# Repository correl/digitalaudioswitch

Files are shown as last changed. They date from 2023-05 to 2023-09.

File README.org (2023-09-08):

#+title: Audio Input and Volume Control

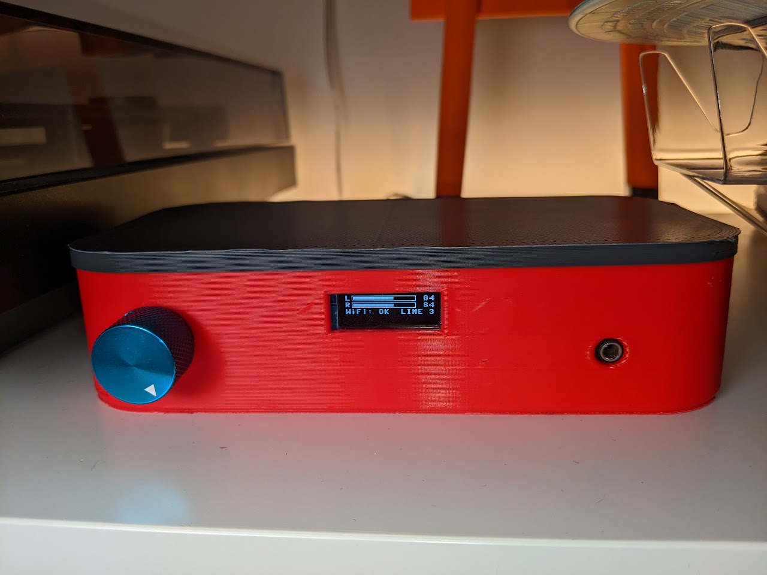
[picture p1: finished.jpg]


* Features
- Switches between three external inputs, outputting through the 3.5mm LINE OUT
  jack.
- Volume control and input switching can be done using the pressable dial on the front
- Current status is displayed on a 128x32 OLED display
- Can be fully controlled via Home Assistant as an [[https://www.home-assistant.io/integrations/mqtt/][MQTT-discoverable]] device.
* Firmware
** Configuration
Create a file named =settings.json= in the project directory with WiFi and MQTT
connection information.

#+begin_src js
  {
      "wifi": {
          "ssid": "MY-SSID",
          "password": "my-wifi-password"
      },
      "mqtt": {
          "broker": "192.168.1.123",
          "prefix": "digital-audio-switch"
      }
  }
#+end_src
** Deploying
Connect the ESP32 to your computer. If you haven't already, [[https://micropython.org/download/esp32/][flash it with the
latest version of MicroPython]], and ensure you have [[https://docs.micropython.org/en/latest/reference/mpremote.html][mpremote installed]].

Running =make= will install dependencies and copy the code and configuration to
the ESP32, resetting it when done.
* Circuit Design
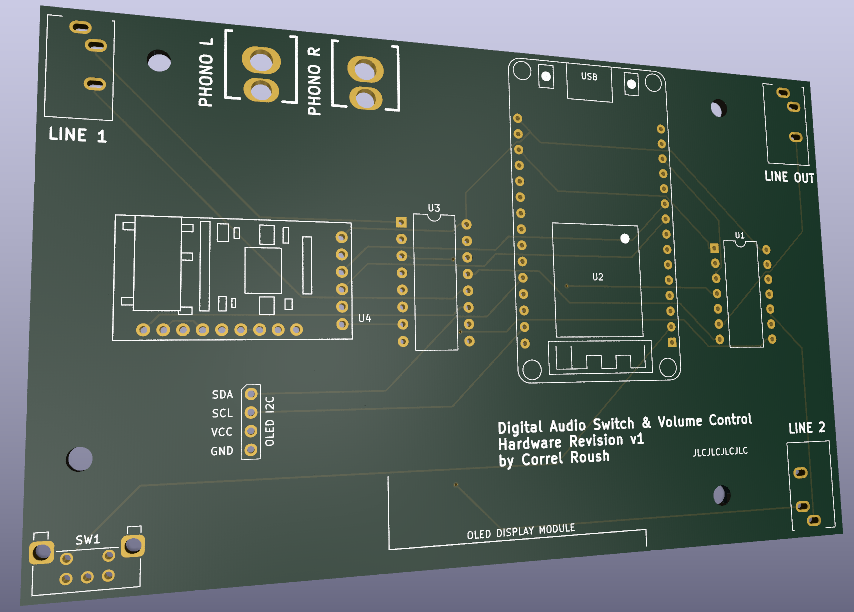
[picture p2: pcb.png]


The schematic and board layout can be found in the [[file:kicad/][kicad]] folder.
* Case
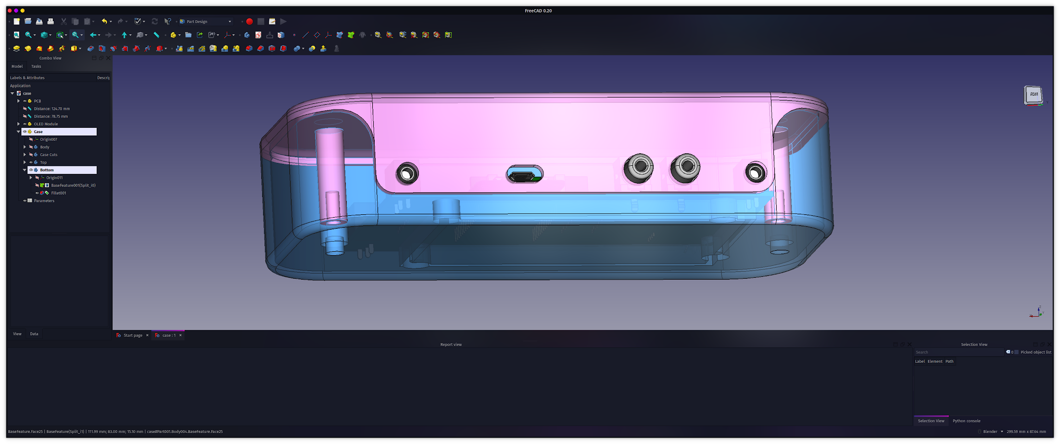
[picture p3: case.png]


The 3D-printable case is built using FreeCAD and can be found in the [[file:freecad/][freecad]]
folder. It is divided into a top and bottom piece. The PCB is affixed using four
M3 threaded inserts and 6mm M3 bolts, the case is assembled using 2 M3 threaded
inserts and 2 10mm M3 bolts.

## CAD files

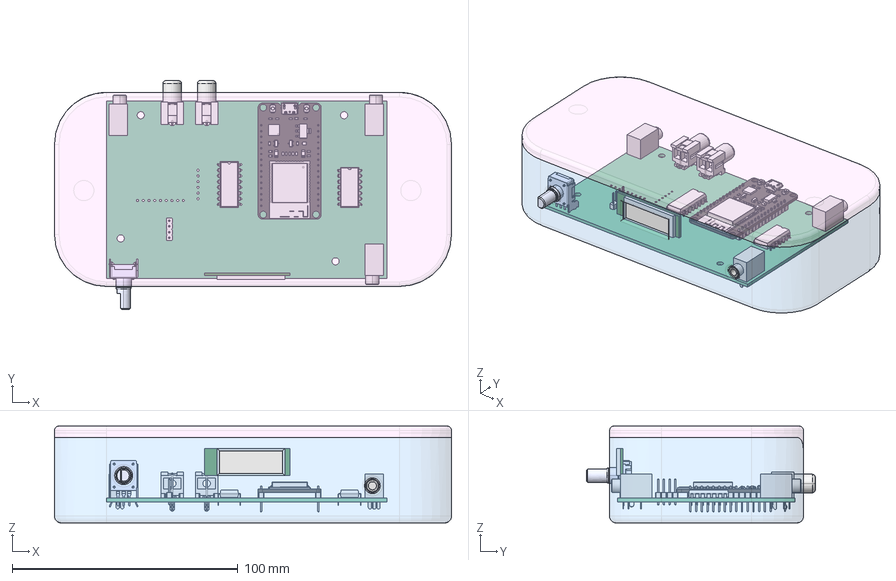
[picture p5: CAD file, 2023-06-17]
freecad/case.FCStd
176.0 x 101.4 x 43.0 mm
Pcb_879ee
J3_CUI_DEVICES_SJ1-3533NG_4473374c59b9 x 3
U3_DIP_16_W1016mm_c0b8a379621b
U2_SW_SPST_B3U-1000P-B_d01e381b36a0 x 2
U2_PinHeader_1x15_P254mm_Vertical_d01e381b36a0[3] x 2
U2_PCB_d01e381b36a0[5]
U2_USB_Micro-B_Molex_47346-0001_d01e381b36a0[6]
U2_LED_1206_3216Metric_d01e381b36a0[7] x 2
U2_CP_EIA_2012_15_AVX_P_d01e381b36a0[9]
U2_SOT_223_d01e381b36a0[10]
U2_R_0603_1608Metric_d01e381b36a0[11] x 12
U2_SOT_23_d01e381b36a0[14] x 2
U2_C_0603_1608Metric_d01e381b36a0[18] x 3
U2_D_0603_d01e381b36a0[19]
U2_QFN-28-1EP_5x5mm_Pitch0.5mm_d01e381b36a0[25]
U2_ESP32-WROOM-32_d01e381b36a0[30]
J4_KLPX_0848A_2_x_a0df84c5cc1c x 2
SW1_PEC12R-2220F-S0024_f3370e811a44
J6_PinHeader_1x04_P254mm_Vertical_046e1bb5b14f
U1_DIP_14_W1016mm_aa2eb500133f
PCB001
Glass
Top
Bottom

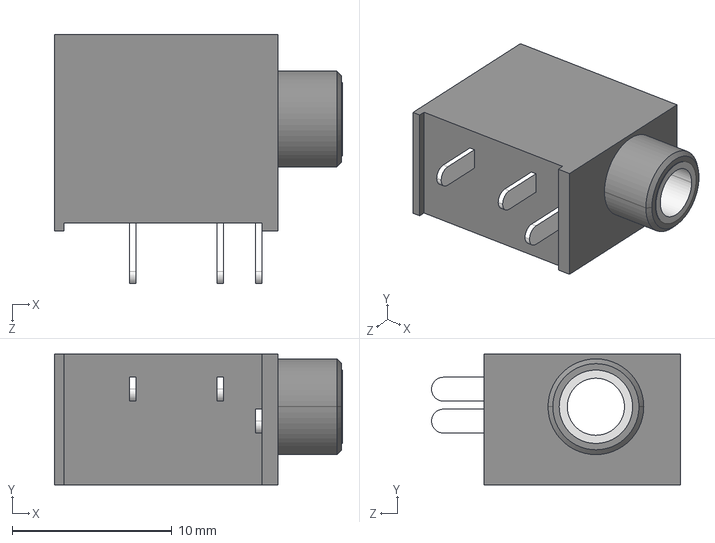
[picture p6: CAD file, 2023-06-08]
kicad/CUI_DEVICES_SJ1-3533NG.step
18.1 x 8.20 x 15.6 mm

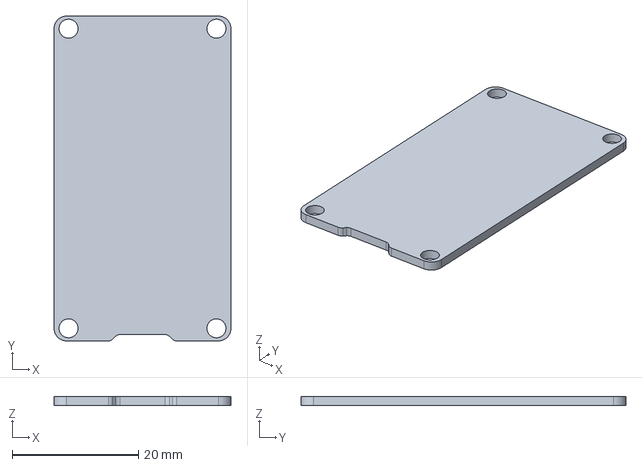
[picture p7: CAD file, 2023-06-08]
kicad/esp32_devkit_v1_doit.step
28.0 x 51.4 x 1.50 mm

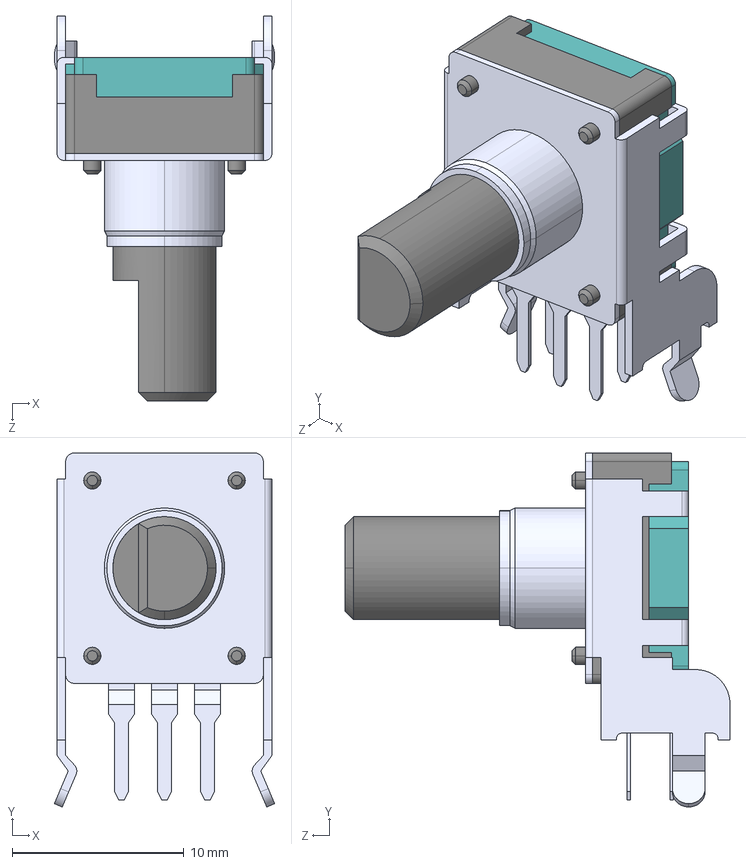
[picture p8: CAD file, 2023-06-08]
kicad/PEC12R-2220F-S0024--3DModel-STEP-1.STEP
12.8 x 20.6 x 22.4 mm

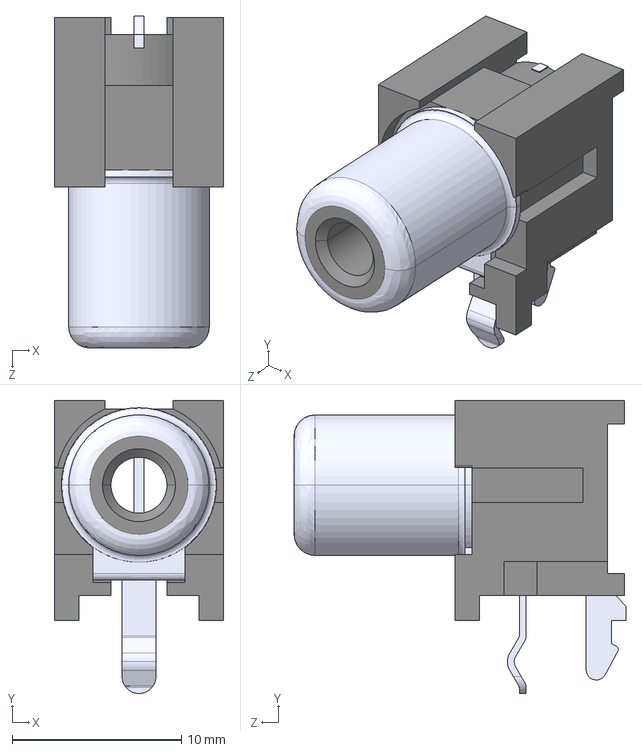
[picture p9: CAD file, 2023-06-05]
kicad/KLPX-0848A-2-x.IGS
10.0 x 17.3 x 19.6 mm

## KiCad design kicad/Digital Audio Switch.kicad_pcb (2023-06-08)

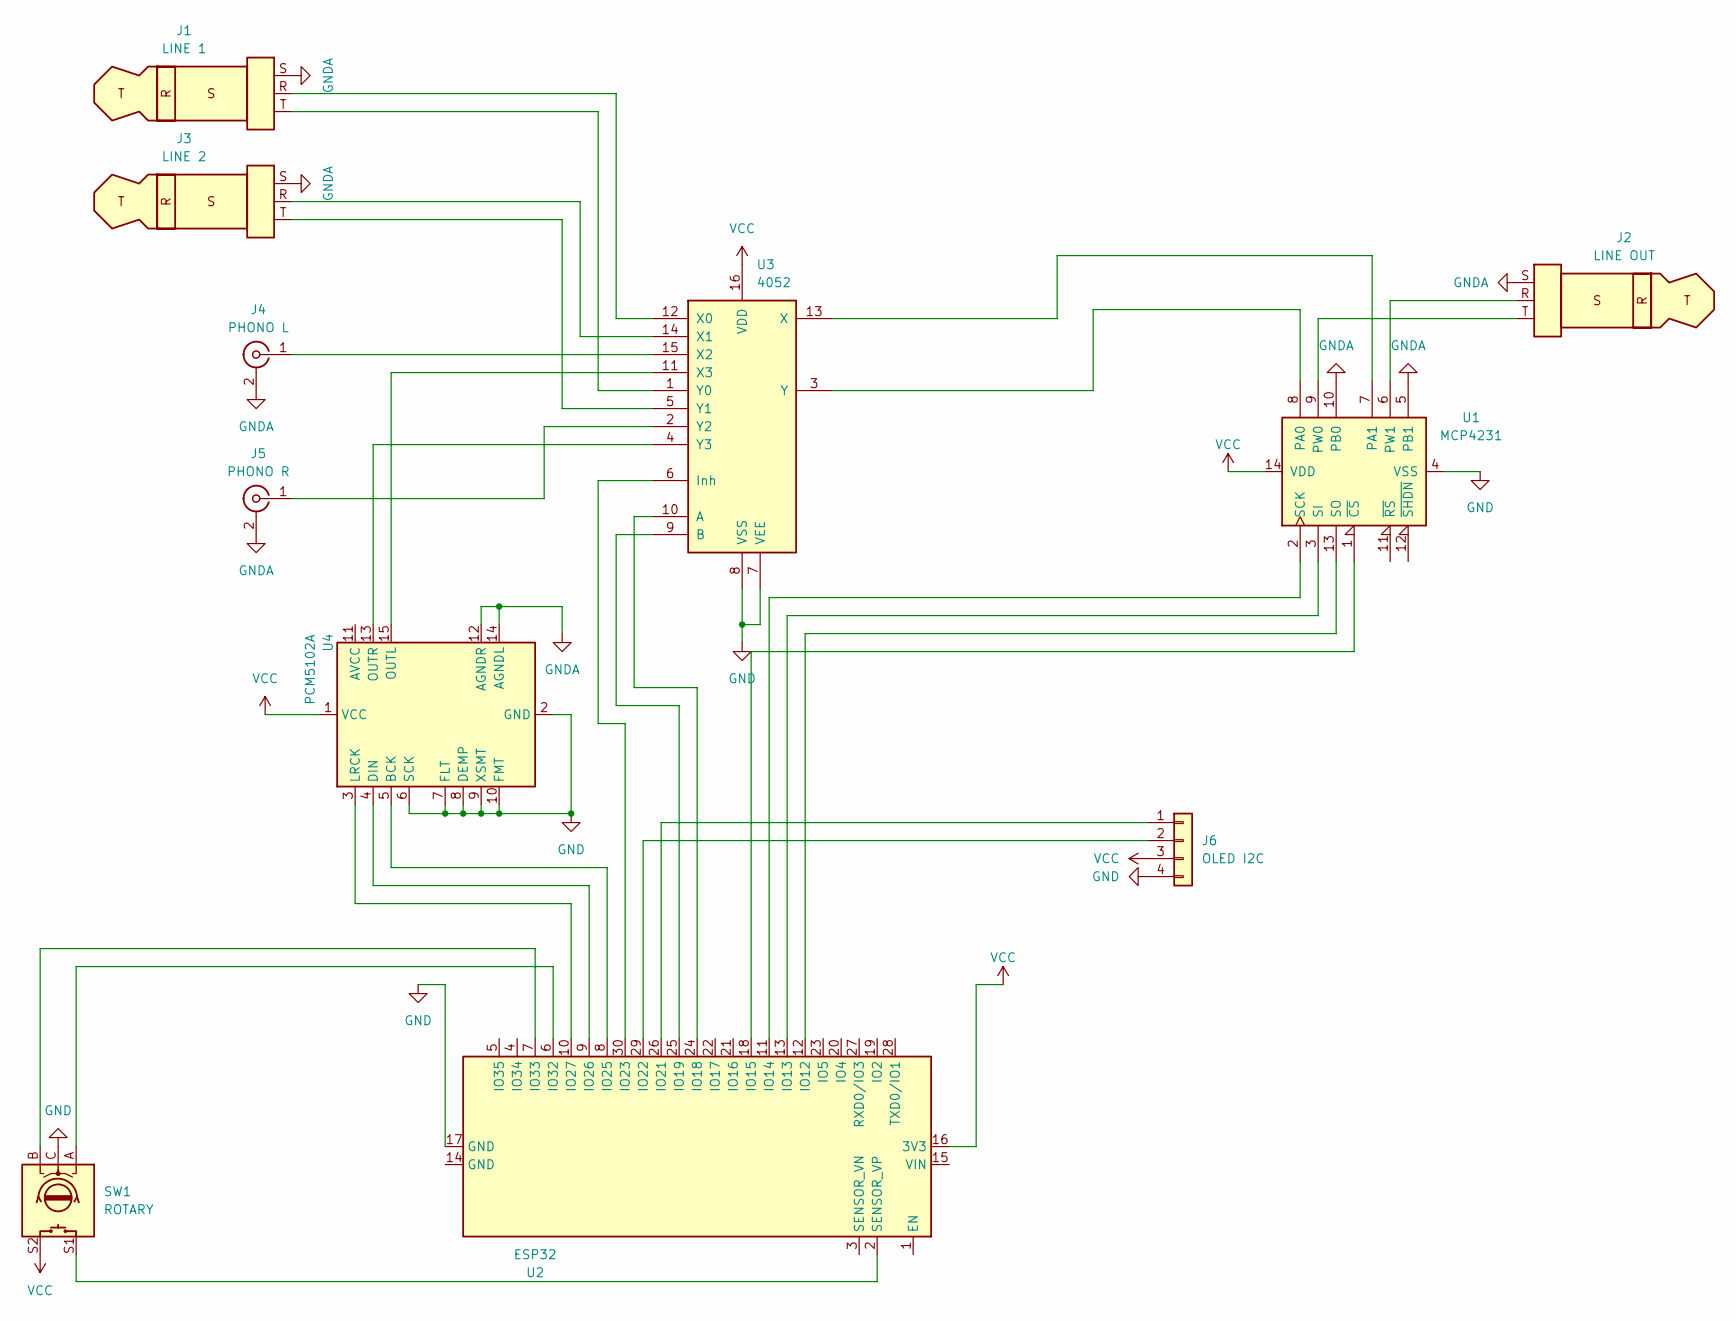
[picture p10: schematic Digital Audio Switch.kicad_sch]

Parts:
J1: LINE 1; Jack_3.5mm_CUI_SJ1-3533NG_Horizontal
J2: LINE OUT; Jack_3.5mm_CUI_SJ1-3533NG_Horizontal
J3: LINE 2; Jack_3.5mm_CUI_SJ1-3533NG_Horizontal
J4: PHONO L; KLPX-0848A
J5: PHONO R; KLPX-0848A
J6: OLED I2C; I2C Pin Header
SW1: ROTARY; RotaryEncoder_Bourns_Horizontal_PEC12R-2xxxF-Sxxxx
U1: MCP4231; DIP-14_W10.16mm
U2: ESP32; esp32_devkit_v1_doit
U3: 4052; DIP-16_W10.16mm
U4: PCM5102A; PCM5102

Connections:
GND: J6.4, SW1.C, U1.4 (VSS), U2.17 (GND), U3.7 (VEE), U3.8 (VSS), U4.2 (GND), U4.6 (SCK), U4.7 (FLT), U4.8 (DEMP), U4.9 (XSMT), U4.10 (FMT)
GNDA: J1.S, J2.S, J3.S, J4.2 (Ext), J5.2 (Ext), U1.5 (PB1), U1.10 (PB0), U4.12 (AGNDR), U4.14 (AGNDL)
unnamed: J4.1 (In), U3.15 (X2)
unnamed: J5.1 (In), U3.2 (Y2)
unnamed: J6.1, U2.26 (IO21)
unnamed: J6.2, U2.29 (IO22)
unnamed: U1.8 (PA0), U3.3 (Y)
unnamed: U1.7 (PA1), U3.13 (X)
unnamed: J2.T, U1.9 (PW0)
unnamed: J2.R, U1.6 (PW1)
unnamed: U1.2 (SCK), U2.11 (IO14)
unnamed: U1.3 (SI), U2.13 (IO13)
unnamed: U1.13 (SO), U2.12 (IO12)
unnamed: U1.1 (~CS), U2.18 (IO15)
unnamed: U2.24 (IO18), U3.10 (A)
unnamed: U2.25 (IO19), U3.9 (B)
unnamed: U2.30 (IO23), U3.6 (Inh)
unnamed: U2.8 (IO25), U4.5 (BCK)
unnamed: U2.9 (IO26), U4.4 (DIN)
unnamed: U2.10 (IO27), U4.3 (LRCK)
unnamed: SW1.A, U2.6 (IO32)
unnamed: SW1.B, U2.7 (IO33)
unnamed: SW1.S1, U2.2 (SENSOR_VP)
unnamed: J1.R, U3.12 (X0)
unnamed: J3.R, U3.14 (X1)
unnamed: U3.11 (X3), U4.15 (OUTL)
unnamed: J1.T, U3.1 (Y0)
unnamed: J3.T, U3.5 (Y1)
unnamed: U3.4 (Y3), U4.13 (OUTR)
VCC: J6.3, SW1.S2, U1.14 (VDD), U2.16 (3V3), U3.16 (VDD), U4.1 (VCC)

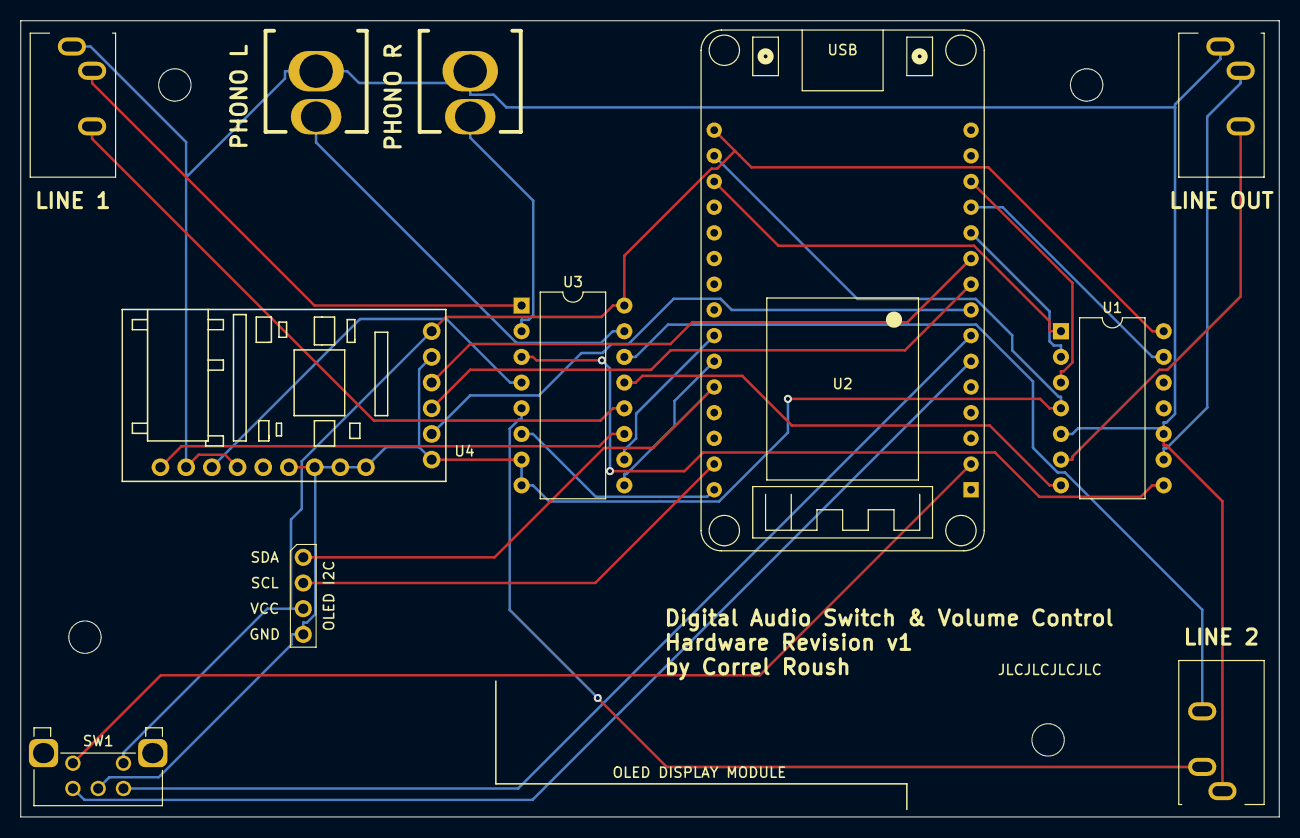
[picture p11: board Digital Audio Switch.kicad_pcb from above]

Board: 2 copper layers, 124.5 x 78.7 mm, 15 parts (0 on the bottom side), 30 nets.

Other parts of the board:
H1, H2, H3, H4: MountingHole_3.2mm_M3

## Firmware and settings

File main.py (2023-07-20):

from machine import Pin, SPI, SoftI2C
import framebuf
import json
import machine
import network
import ubinascii
import uasyncio
import utime

from umqtt.simple import MQTTClient

import cd4052
import ssd1306
import mcp4
from button import Button
from rotary_irq_esp import RotaryIRQ
from statetree import StateTree

VOLUME_MAX = const(128)

MQTT_KEEPALIVE = const(60)
MQTT_UPDATE_INTERVAL = const(60)
MQTT_RECONNECT_INTERVAL = const(60)

channels = ["LINE 1", "LINE 2", "PHONO", "DAC"]
state = StateTree(
    {
        "network": "OFF",
        "volume": {
            "left": 0,
            "right": 0,
            "muted": "OFF",
        },
        "channel": channels[0],
    }
)
last_update = 0

rotary = RotaryIRQ(
    33,
    32,
    0,
    max_val=128,
    range_mode=RotaryIRQ.RANGE_BOUNDED,
    pull_up=True,
    incr=4,
)
rotary_value = rotary.value()
rotary_button = Button(Pin(36, Pin.IN))

try:
    i2c = SoftI2C(sda=Pin(21), scl=Pin(22))
    oled_width = const(128)
    oled_height = const(32)
    oled = ssd1306.SSD1306_I2C(oled_width, oled_height, i2c)
except Exception as e:
    print("WARNING: OLED unavailable:", e)
    oled = None

switch = cd4052.CD4052(18, 19, 23)
switch.select(0)

sta_if = network.WLAN(network.STA_IF)

spi = SPI(1)
cs = Pin(15, mode=Pin.OUT, value=1)
pot = mcp4.MCP4(spi, cs)

with open("settings.json", "r") as f:
    settings = json.load(f)

mqtt = None
mqtt_client_id = ubinascii.hexlify(machine.unique_id())
mqtt_broker = settings["mqtt"]["broker"]
mqtt_prefix = settings["mqtt"]["prefix"]
last_mqtt_attempt = 0


def mqtt_init():
    print("Starting MQTT client")
    mqtt = MQTTClient(mqtt_client_id, mqtt_broker, keepalive=MQTT_KEEPALIVE)
    mqtt.set_callback(on_message)
    mqtt.set_last_will(f"{mqtt_prefix}/status", b"offline", retain=True)
    mqtt.connect()
    mqtt.subscribe(f"{mqtt_prefix}/set")
    mqtt_device = {
        "identifiers": mqtt_client_id,
        "manufacturer": "correl",
        "model": "digital-audio-switch",
        "name": "Digital Audio Switch",
    }

    mqtt.publish(
        f"homeassistant/number/digital-audio-switch/volume-left/config".encode(),
        json.dumps(
            {
                "name": "Digital Audio Switch Volume (Left)",
                "command_topic": f"{mqtt_prefix}/set",
                "command_template": '{"volume": {"left": {{value}}}}',
                "state_topic": f"{mqtt_prefix}/state",
                "value_template": "{{ value_json.volume.left }}",
                "availability_topic": f"{mqtt_prefix}/status",
                "min": 0,
                "max": VOLUME_MAX,
                "mode": "slider",
                "step": 1,
                "unique_id": "digital-audio-switch-volume-left",
                "device": mqtt_device,
            }
        ).encode(),
        retain=True,
    )
    mqtt.publish(
        f"homeassistant/number/digital-audio-switch/volume-right/config".encode(),
        json.dumps(
            {
                "name": "Digital Audio Switch Volume (Right)",
                "command_topic": f"{mqtt_prefix}/set",
                "command_template": '{"volume": {"right": {{value}}}}',
                "state_topic": f"{mqtt_prefix}/state",
                "value_template": "{{ value_json.volume.right }}",
                "availability_topic": f"{mqtt_prefix}/status",
                "min": 0,
                "max": VOLUME_MAX,
                "mode": "slider",
                "step": 1,
                "unique_id": "digital-audio-switch-volume-right",
                "device": mqtt_device,
            }
        ).encode(),
        retain=True,
    )
    mqtt.publish(
        f"homeassistant/number/digital-audio-switch/volume-master/config".encode(),
        json.dumps(
            {
                "name": "Digital Audio Switch Volume (Master)",
                "command_topic": f"{mqtt_prefix}/set",
                "command_template": '{"volume": {"right": {{value}}, "left": {{value}}}}',
                "state_topic": f"{mqtt_prefix}/state",
                "value_template": """
                            {%set values = value_json.volume.left,
                                           value_json.volume.right %}
                            {{ values|max }}
                        """,
                "availability_topic": f"{mqtt_prefix}/status",
                "min": 0,
                "max": VOLUME_MAX,
                "mode": "slider",
                "step": 1,
                "unique_id": "digital-audio-switch-volume-master",
                "device": mqtt_device,
            }
        ).encode(),
        retain=True,
    )
    mqtt.publish(
        f"homeassistant/switch/digital-audio-switch/mute/config".encode(),
        json.dumps(
            {
                "name": "Digital Audio Switch Mute",
                "command_topic": f"{mqtt_prefix}/set",
                "payload_on": '{"volume": {"muted": "ON"}}',
                "payload_off": '{"volume": {"muted": "OFF"}}',
                "state_on": "ON",
                "state_off": "OFF",
                "state_topic": f"{mqtt_prefix}/state",
                "value_template": "{{ value_json.volume.muted }}",
                "availability_topic": f"{mqtt_prefix}/status",
                "unique_id": "digital-audio-switch-volume-mute",
                "device": mqtt_device,
            }
        ).encode(),
        retain=True,
    )
    mqtt.publish(
        f"homeassistant/select/digital-audio-switch/channel/config".encode(),
        json.dumps(
            {
                "name": "Digital Audio Switch Channel",
                "command_topic": f"{mqtt_prefix}/set",
                "command_template": '{"channel": "{{value}}"}',
                "state_topic": f"{mqtt_prefix}/state",
                "value_template": "{{ value_json.channel }}",
                "availability_topic": f"{mqtt_prefix}/status",
                "options": channels,
                "unique_id": "digital-audio-switch-channel",
                "device": mqtt_device,
            }
        ).encode(),
        retain=True,
    )
    return mqtt


def on_message(topic, msg):
    print(f"MQTT <- [{topic}] {msg}")
    try:
        msg = json.loads(msg)
    except:
        return
    if volume := msg.get("volume"):
        if isinstance(volume.get("left"), int):
            pot.write(0, volume["left"])
        if isinstance(volume.get("right"), int):
            pot.write(1, volume["right"])
        if isinstance(volume.get("muted"), str):
            switch.mute(volume["muted"] == "ON")
    if isinstance(msg.get("channel"), str):
        try:
            switch.select(channels.index(msg["channel"]))
        except ValueError:
            print("WARNING: Attempted to select invalid channel", msg["channel"])


def loop():
    global mqtt, state, last_update, last_mqtt_attempt
    global rotary, rotary_button, rotary_value

    rotary_button.update()
    if rotary_button.was_clicked():
        switch.toggle_mute()
    if rotary_button.was_double_clicked():
        if switch.channel() >= 3:
            switch.select(0)
        else:
            switch.select(switch.channel() + 1)

    state["volume"]["left"] = pot.read(0)
    state["volume"]["right"] = pot.read(1)
    state["volume"]["muted"] = "ON" if switch.muted() else "OFF"
    state["channel"] = channels[switch.channel()]

    if state.changed:
        # Volume changed externally
        rotary.set(value=max(state["volume"]["left"], state["volume"]["right"]))
        rotary_value = rotary.value()

    new_value = rotary.value()
    if rotary_value != new_value:
        print("Rotary:", new_value)
        state["volume"]["left"] = new_value
        state["volume"]["right"] = new_value
        pot.write(0, new_value)
        pot.write(1, new_value)
        rotary_value = new_value

    if not sta_if.active():
        print("Connecting to WiFi")
        sta_if.active(True)
        sta_if.connect(settings["wifi"]["ssid"], settings["wifi"]["password"])

    if sta_if.active() and not sta_if.isconnected():
        state["network"] = "ACT"
    if sta_if.isconnected():
        ip, _, _, _ = sta_if.ifconfig()
        if ip == "0.0.0.0":
            # Something went wrong, try to reconnect
            print("IP invalid, retrying WiFi connection")
            state["network"] = "ACT"
            sta_if.active(True)
            sta_if.connect(settings["wifi"]["ssid"], settings["wifi"]["password"])
        elif state["network"] != "OK":
            print(f"WIFI Connected to {sta_if.config('ssid')}")
            print(f"IP Address: {ip}")
            state["network"] = "OK"
        if not mqtt and utime.time() - last_mqtt_attempt >= MQTT_RECONNECT_INTERVAL:
            last_mqtt_attempt = utime.time()
            try:
                mqtt = mqtt_init()
            except OSError as e:
                print(f"Failed to connect to MQTT ({mqtt_broker}): {e}")
        if mqtt:
            if state.changed or utime.time() - last_update >= MQTT_UPDATE_INTERVAL:
                topic = f"{mqtt_prefix}/state".encode()
                payload = json.dumps(state.dictionary).encode()
                print(f"MQTT -> [{topic}] {payload}")
                mqtt.publish(f"{mqtt_prefix}/status", b"online", retain=True)
                mqtt.publish(topic, payload, retain=True)
                last_update = utime.time()
            mqtt.check_msg()
    if oled and state.changed:
        oled.fill(0)
        oled.framebuf.rect(10, 0, 92, 8, 1)
        oled.framebuf.rect(
            12, 2, round(state["volume"]["left"] / VOLUME_MAX * 88), 4, 1, True
        )
        oled.framebuf.rect(10, 10, 92, 8, 1)
        oled.framebuf.rect(
            12, 12, round(state["volume"]["right"] / VOLUME_MAX * 88), 4, 1, True
        )
        oled.text("L", 0, 0)
        oled.text("R", 0, 10)
        oled.text(f"{state['volume']['left']:3d}", 104, 0)
        oled.text(f"{state['volume']['right']:3d}", 104, 10)
        if state["volume"]["muted"] == "ON":
            oled.framebuf.rect(40, 4, 4 * 8 + 2, 10, 0, True)
            oled.framebuf.rect(39, 3, 4 * 8 + 4, 12, 1)
            oled.framebuf.rect(38, 2, 4 * 8 + 6, 14, 0)
            oled.text("MUTE", 41, 5)
        oled.text(f"WiFi: {state['network']}", 0, 20)
        oled.text(f'{state["channel"]:>6}', 80, 20)
        oled.show()
    state.clean()


while True:
    loop()
    utime.sleep_ms(10)

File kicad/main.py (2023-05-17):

from machine import Pin, SPI, SoftI2C
import framebuf
import ssd1306
import mcp4


i2c = SoftI2C(sda=Pin(2), scl=Pin(16))
oled_width = 128
oled_height = 32
oled = ssd1306.SSD1306_I2C(oled_width, oled_height, i2c)
buf = bytearray((oled_height // 8) * oled_width)
fbuf = framebuf.FrameBuffer1(buf, oled_width, oled_height)


spi = SPI(1)
cs = Pin(15, mode=Pin.OUT, value=1)
pot = mcp4.MCP4(spi, cs)


def update():
    PW0 = pot.read(0)
    PW1 = pot.read(1)
    oled.fill(0)
    oled.text(f"PW0: {PW0}", 0, 0)
    oled.text(f"PW1: {PW1}", 0, 10)
    oled.show()


update()

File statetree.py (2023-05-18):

class StateTree:
    """A dictionary-like object that tracks when values have been changed."""

    def __init__(self, dictionary: dict = None, parent: "StateTree" = None) -> None:
        """Create a new state tree.

        If a dictionary is supplied, its values will be initialized with it and
        the tree will be marked as clean.

        If a parent is supplied, the parent will be marked as dirty when this
        tree is modified.

        """
        self._dictionary = dictionary if dictionary else dict()
        self._parent = parent
        self._changed = False

    def dirty(self):
        """Mark the tree as dirty.

        This is done automatically whenever an item is updated.

        """
        self._changed = True
        if self._parent:
            self._parent.dirty()

    def clean(self):
        """Mark the tree as clean.

        Use this method to reset the changed status of the tree once after
        you've reacted to it being updated.

        """
        self._changed = False

    @property
    def changed(self):
        """Returns whether the tree has been modified since the last time it was
        marked as clean."""
        return self._changed

    @property
    def dictionary(self):
        """Returns the underlying dictionary."""
        return self._dictionary

    def __getitem__(self, *args, **kwargs):
        """Get the value stored in a key in the tree.

        If the value is a dictionary, returns a StateTree object instead that
        will notify the parent if a change is made.

        """
        o = self._dictionary.__getitem__(*args, **kwargs)
        if isinstance(o, dict):
            return StateTree(o, parent=self)
        else:
            return o

    def __setitem__(self, key, value):
        """Update the value of a key in the tree.

        Marks the tree as changed if the key is new or the new value differs
        from the current value.

        """
        if key not in self._dictionary or value != self._dictionary[key]:
            self.dirty()
        self._dictionary[key] = value

    def __repr__(self):
        return "<StateTree{}{} {}>".format(
            "^" if self._parent else "",
            "*" if self._changed else "",
            repr(self._dictionary),
        )

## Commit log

2023-05-28 Add multiplexing switch
2023-05-28 Update switch select log message
2023-05-28 Add mute and input switching button controls
2023-06-05 Add KiCad design
    [Digital Audio Switch.kicad_pcb, Digital Audio Switch.kicad_sch, KLPX-0848A-2-x.IGS]
2023-06-05 Polish PCB design
    [Digital Audio Switch.kicad_pcb, Digital Audio Switch.kicad_sch]
2023-06-06 Set gerber export settings
    [Digital Audio Switch.kicad_pcb]
2023-06-06 Ignore generated gerber files
2023-06-06 Add initial OpenSCAD case files
    [case.scad]
2023-06-06 Generate a basic case bottom with PCB mounting holes
    [case.scad, pcb_mount.scad]
2023-06-07 Add multiple export options to the case design
    [case.scad]
2023-06-08 Add additional part models
    [Digital Audio Switch.kicad_pcb, Digital Audio Switch.kicad_sch, PEC12R-2220F-S0024--3DModel-STEP-1.STEP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]
2023-06-08 Add audio jack 3d model
    [CUI_DEVICES_SJ1-3533NG.step, Digital Audio Switch.kicad_pcb]
2023-06-08 Add an initial case design in FreeCAD
    [case.FCStd]
2023-06-13 Update case design with split top and bottom
    [case.FCStd]
2023-06-17 Polish up the freecad case
    [case.FCStd]
2023-06-17 Set the rotary increment to 4, 1 is way too slow
    [main.py]
2023-06-17 Update readme to reference the FreeCAD case design
2023-07-08 Handle MQTT connection failures
    [main.py]

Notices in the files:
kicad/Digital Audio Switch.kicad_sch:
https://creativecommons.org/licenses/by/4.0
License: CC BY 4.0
